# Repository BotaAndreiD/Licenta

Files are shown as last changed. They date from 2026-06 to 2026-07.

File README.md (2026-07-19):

# CardioMed — Portable ECG Acquisition & Monitoring System

**Bachelor's Thesis · Technical University of Cluj-Napoca**
Faculty of Electronics, Telecommunications and Information Technology — 2026

A low-cost, single-lead ECG acquisition and monitoring system built around a **discrete analog front-end** instead of an integrated AFE chip — designed to meet the essential requirements of **IEC 60601-2-25** while staying affordable enough for continuous home use.

---

## Overview

Clinical-grade electrocardiographs remain largely confined to hospitals due to their cost and complexity. CardioMed explores an alternative: a fully discrete analog signal chain — individually optimized filter stages, an instrumentation amplifier, and an active common-mode rejection loop — paired with a companion desktop application that detects heartbeats in real time and generates clinical reports automatically.

Every design decision, from a single capacitor value to the ADC sample rate, is traced back to a specific requirement of the medical standard — a principle referred to throughout the project as **vertical traceability**.

## Key Results

| Parameter | Standard Requirement (IEC 60601-2-25) | Achieved |
|---|---|---|
| Input-referred noise | ≤ 30 µV p-p | **10.76 µV** |
| Passband | 50 mHz – 150 Hz | 49.67 mHz – 150.71 Hz |
| System CMRR | ≥ 89 dB | **123 – 137 dB** |
| Defibrillation protection | ≥ 5000 V | 5000 V |
| Patient fault current | ≤ 10 µA | **3.3 µA** |
| R-wave detection sensitivity (MIT-BIH) | — | **91.5%** |
| Unit cost (BOM, 1,000 units) | — | **~130 RON** |

## System Architecture

```mermaid
flowchart LR
    A[ECG Electrodes] --> B[Protection Network]
    B --> C[Right Leg Drive Loop]
    B --> D["Instrumentation Amplifier (MAX41400)"]
    D --> E["Active Filters: Bessel HPF + Twin-T Notch + Butterworth LPF"]
    E --> F["24-bit ADC (AD7124-4)"]
    F --> G["ESP32-C3 — BLE Transmission"]
    G --> H["Desktop App (C# / WPF)"]
    H --> I["PQRST Detection + Clinical Report (PDF)"]
```

- **Analog front-end** — two-stage TVS/Zener input protection, a Right Leg Drive loop for active common-mode cancellation, a MAX41400 instrumentation amplifier, and a cascade of Bessel high-pass, Twin-T notch, and Butterworth low-pass active filters.
- **Digitization & wireless link** — 24-bit AD7124-4 ADC feeding an ESP32-C3, streaming digitized ECG samples over Bluetooth Low Energy.
- **PCB** — compact 4-layer board (82×46 mm) designed in KiCad, with physically separated analog and digital domains and length-matched differential input traces.
- **Desktop application** — a C#/WPF app performing real-time PQRST detection (Pan–Tompkins-derived algorithm), computing 7 clinical parameters (heart rate, PR/QRS/QTc intervals, SDNN, R-wave amplitude, ectopic-beat count), and auto-generating signed PDF reports.
- **Validation** — the full analog chain was validated in LTSpice against a real ECG signal (MIT-BIH Normal Sinus Rhythm Database) with a realistic interference model; the detection algorithms were separately validated against the public MIT-BIH Arrhythmia and QT Databases (PhysioNet).

## Repository Structure

```
├── AchizitionareSemnal/         # Signal acquisition & analysis
├── Documentatie/                # Full thesis document & synthesis
├── ESP32BLE+InterfataDigitala/  # ESP32-C3 firmware, BLE link, and the C#/WPF monitoring app
├── PCB_REVC/                    # KiCad schematic, PCB layout, and Gerbers
├── SimulariLtspice/             # LTSpice simulations of the analog chain
├── SSET/                        # Student symposium presentation materials
└── Licenta_EA_TST_2024-2025/    # Project archive
```

## Tools & Technologies

`LTspice` · `KiCad` · `Embedded C` · `Python` · `C# / WPF` · `Bluetooth Low Energy` · `MIT-BIH / PhysioNet datasets`

## Standards

Designed against **IEC 60601-2-25** (electrocardiograph performance) and **IEC 60601-1** (basic electrical safety).

## Author

**Bota Andrei-Daniel** — Applied Electronics, Technical University of Cluj-Napoca
[GitHub](https://github.com/BotaAndreiD) · [LinkedIn](https://www.linkedin.com/in/andrei-bota-283269297/)

## Acknowledgments

Thanks to my thesis advisor and to Analog Devices, where an earlier internship shaped much of the analog design approach used in this project.

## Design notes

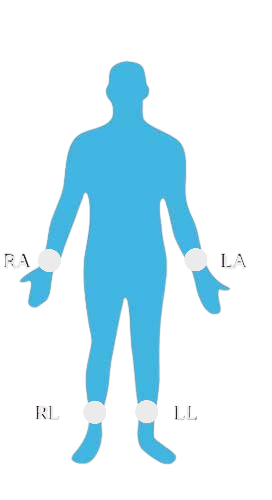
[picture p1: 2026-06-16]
ESP32BLE+InterfataDigitala/ECGMonitor/electrod1.png

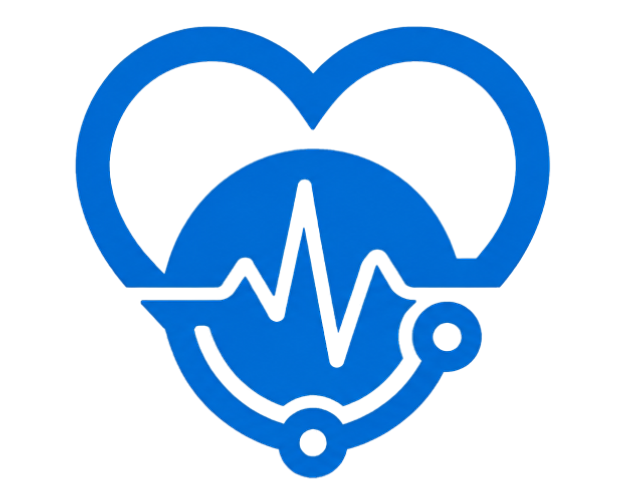
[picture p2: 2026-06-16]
ESP32BLE+InterfataDigitala/ECGMonitor/Sigla.png

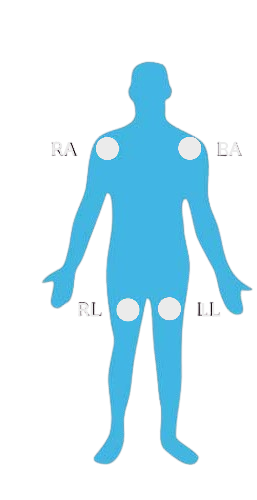
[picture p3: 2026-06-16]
ESP32BLE+InterfataDigitala/ECGMonitor/electrod2.png

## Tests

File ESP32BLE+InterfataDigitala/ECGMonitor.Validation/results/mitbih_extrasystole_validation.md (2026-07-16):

Validare detecție extrasistole (bătăi premature/ectopice) — MIT-BIH Arrhythmia Database (44 înregistrări, fereastră de potrivire ±100 ms)

| Înregistrare | Bătăi reale | Detectate | TP | FN | FP | Se (%) | +P (%) |
|---|---|---|---|---|---|---|---|
| 101 | 3 | 9 | 2 | 1 | 7 | 66.67 | 22.22 |
| 106 | 520 | 309 | 269 | 251 | 40 | 51.73 | 87.06 |
| 108 | 23 | 60 | 9 | 14 | 51 | 39.13 | 15.00 |
| 109 | 40 | 5 | 3 | 37 | 2 | 7.50 | 60.00 |
| 112 | 2 | 4 | 1 | 1 | 3 | 50.00 | 25.00 |
| 114 | 59 | 38 | 2 | 57 | 36 | 3.39 | 5.26 |
| 115 | 0 | 3 | 0 | 0 | 3 | 0.00 | 0.00 |
| 116 | 110 | 115 | 106 | 4 | 9 | 96.36 | 92.17 |
| 118 | 112 | 43 | 29 | 83 | 14 | 25.89 | 67.44 |
| 119 | 444 | 432 | 429 | 15 | 3 | 96.62 | 99.31 |
| 122 | 0 | 1 | 0 | 0 | 1 | 0.00 | 0.00 |
| 124 | 83 | 6 | 0 | 83 | 6 | 0.00 | 0.00 |
| 201 | 328 | 149 | 50 | 278 | 99 | 15.24 | 33.56 |
| 203 | 447 | 415 | 75 | 372 | 340 | 16.78 | 18.07 |
| 205 | 85 | 37 | 18 | 67 | 19 | 21.18 | 48.65 |
| 207 | 212 | 179 | 72 | 140 | 107 | 33.96 | 40.22 |
| 208 | 1367 | 357 | 342 | 1025 | 15 | 25.02 | 95.80 |
| 209 | 384 | 46 | 25 | 359 | 21 | 6.51 | 54.35 |
| 215 | 168 | 135 | 106 | 62 | 29 | 63.10 | 78.52 |
| 220 | 94 | 29 | 26 | 68 | 3 | 27.66 | 89.66 |
| 223 | 560 | 97 | 90 | 470 | 7 | 16.07 | 92.78 |
| 230 | 1 | 8 | 0 | 1 | 8 | 0.00 | 0.00 |
| 100 | 34 | 21 | 20 | 14 | 1 | 58.82 | 95.24 |
| 103 | 2 | 5 | 0 | 2 | 5 | 0.00 | 0.00 |
| 105 | 41 | 84 | 37 | 4 | 47 | 90.24 | 44.05 |
| 111 | 1 | 0 | 0 | 1 | 0 | 0.00 | 0.00 |
| 113 | 6 | 5 | 0 | 6 | 5 | 0.00 | 0.00 |
| 117 | 1 | 4 | 0 | 1 | 4 | 0.00 | 0.00 |
| 121 | 2 | 25 | 1 | 1 | 24 | 50.00 | 4.00 |
| 123 | 3 | 2 | 0 | 3 | 2 | 0.00 | 0.00 |
| 200 | 858 | 217 | 188 | 670 | 29 | 21.91 | 86.64 |
| 202 | 75 | 79 | 38 | 37 | 41 | 50.67 | 48.10 |
| 210 | 226 | 155 | 91 | 135 | 64 | 40.27 | 58.71 |
| 212 | 0 | 7 | 0 | 0 | 7 | 0.00 | 0.00 |
| 213 | 610 | 300 | 288 | 322 | 12 | 47.21 | 96.00 |
| 214 | 257 | 205 | 184 | 73 | 21 | 71.60 | 89.76 |
| 219 | 72 | 95 | 26 | 46 | 69 | 36.11 | 27.37 |
| 221 | 396 | 358 | 314 | 82 | 44 | 79.29 | 87.71 |
| 222 | 209 | 259 | 113 | 96 | 146 | 54.07 | 43.63 |
| 228 | 365 | 366 | 320 | 45 | 46 | 87.67 | 87.43 |
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
| **TOTAL** | | | **3768** | **6719** | **1503** | **35.93** | **71.49** |

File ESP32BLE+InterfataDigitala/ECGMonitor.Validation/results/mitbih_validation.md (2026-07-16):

Validare detector R — MIT-BIH Arrhythmia Database (44 înregistrări, fereastră de potrivire ±100 ms)

| Înregistrare | Bătăi reale | Detectate | TP | FN | FP | Se (%) | +P (%) |
|---|---|---|---|---|---|---|---|
| 101 | 1865 | 1852 | 1843 | 22 | 9 | 98.82 | 99.51 |
| 106 | 2027 | 2008 | 1885 | 142 | 123 | 92.99 | 93.87 |
| 108 | 1763 | 2357 | 1463 | 300 | 894 | 82.98 | 62.07 |
| 109 | 2532 | 2492 | 2128 | 404 | 364 | 84.04 | 85.39 |
| 112 | 2539 | 2517 | 2488 | 51 | 29 | 97.99 | 98.85 |
| 114 | 1879 | 1872 | 1618 | 261 | 254 | 86.11 | 86.43 |
| 115 | 1953 | 1936 | 1917 | 36 | 19 | 98.16 | 99.02 |
| 116 | 2412 | 2391 | 2369 | 43 | 22 | 98.22 | 99.08 |
| 118 | 2278 | 2267 | 1561 | 717 | 706 | 68.53 | 68.86 |
| 119 | 1987 | 1983 | 1976 | 11 | 7 | 99.45 | 99.65 |
| 122 | 2476 | 2436 | 2435 | 41 | 1 | 98.34 | 99.96 |
| 124 | 1619 | 1539 | 1500 | 119 | 39 | 92.65 | 97.47 |
| 201 | 1963 | 1885 | 1778 | 185 | 107 | 90.58 | 94.32 |
| 203 | 2980 | 3041 | 2738 | 242 | 303 | 91.88 | 90.04 |
| 205 | 2656 | 2630 | 2578 | 78 | 52 | 97.06 | 98.02 |
| 207 | 2332 | 2276 | 762 | 1570 | 1514 | 32.68 | 33.48 |
| 208 | 2955 | 2924 | 2902 | 53 | 22 | 98.21 | 99.25 |
| 209 | 3005 | 3009 | 2915 | 90 | 94 | 97.00 | 96.88 |
| 215 | 3363 | 3360 | 3051 | 312 | 309 | 90.72 | 90.80 |
| 220 | 2048 | 2033 | 1976 | 72 | 57 | 96.48 | 97.20 |
| 223 | 2605 | 2557 | 2330 | 275 | 227 | 89.44 | 91.12 |
| 230 | 2256 | 2217 | 1873 | 383 | 344 | 83.02 | 84.48 |
| 100 | 2273 | 2259 | 2255 | 18 | 4 | 99.21 | 99.82 |
| 103 | 2084 | 2040 | 2034 | 50 | 6 | 97.60 | 99.71 |
| 105 | 2572 | 2603 | 2507 | 65 | 96 | 97.47 | 96.31 |
| 111 | 2124 | 2051 | 2018 | 106 | 33 | 95.01 | 98.39 |
| 113 | 1795 | 1789 | 1733 | 62 | 56 | 96.55 | 96.87 |
| 117 | 1535 | 1529 | 1228 | 307 | 301 | 80.00 | 80.31 |
| 121 | 1863 | 1854 | 1826 | 37 | 28 | 98.01 | 98.49 |
| 123 | 1518 | 1493 | 1405 | 113 | 88 | 92.56 | 94.11 |
| 200 | 2601 | 2654 | 1973 | 628 | 681 | 75.86 | 74.34 |
| 202 | 2136 | 2121 | 2106 | 30 | 15 | 98.60 | 99.29 |
| 210 | 2650 | 2653 | 2546 | 104 | 107 | 96.08 | 95.97 |
| 212 | 2748 | 2753 | 2729 | 19 | 24 | 99.31 | 99.13 |
| 213 | 3251 | 3225 | 3179 | 72 | 46 | 97.79 | 98.57 |
| 214 | 2262 | 2222 | 2170 | 92 | 52 | 95.93 | 97.66 |
| 219 | 2154 | 2133 | 2129 | 25 | 4 | 98.84 | 99.81 |
| 221 | 2427 | 2416 | 2406 | 21 | 10 | 99.13 | 99.59 |
| 222 | 2483 | 2487 | 2452 | 31 | 35 | 98.75 | 98.59 |
| 228 | 2053 | 2116 | 1971 | 82 | 145 | 96.01 | 93.15 |
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
| **TOTAL** | | | **92634** | **8571** | **8476** | **91.53** | **91.62** |

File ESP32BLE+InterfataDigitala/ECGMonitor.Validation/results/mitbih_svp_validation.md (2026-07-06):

Validare detecție extrasistole SUPRAVENTRICULARE (nodal/atrial) — MIT-BIH Arrhythmia Database. NOTĂ: +P e o limită inferioară — o detecție care corespunde corect unei bătăi ventriculare (V/aberant/fuziune, cod 4/5/6) apare aici drept FP. (44 înregistrări, fereastră de potrivire ±100 ms)

| Înregistrare | Bătăi reale | Detectate | TP | FN | FP | Se (%) | +P (%) |
|---|---|---|---|---|---|---|---|
| 101 | 3 | 9 | 2 | 1 | 7 | 66.67 | 22.22 |
| 106 | 0 | 309 | 0 | 0 | 309 | 0.00 | 0.00 |
| 108 | 4 | 60 | 3 | 1 | 57 | 75.00 | 5.00 |
| 109 | 0 | 5 | 0 | 0 | 5 | 0.00 | 0.00 |
| 112 | 2 | 4 | 1 | 1 | 3 | 50.00 | 25.00 |
| 114 | 12 | 38 | 1 | 11 | 37 | 8.33 | 2.63 |
| 115 | 0 | 3 | 0 | 0 | 3 | 0.00 | 0.00 |
| 116 | 1 | 115 | 1 | 0 | 114 | 100.00 | 0.87 |
| 118 | 96 | 43 | 17 | 79 | 26 | 17.71 | 39.53 |
| 119 | 0 | 432 | 0 | 0 | 432 | 0.00 | 0.00 |
| 122 | 0 | 1 | 0 | 0 | 1 | 0.00 | 0.00 |
| 124 | 31 | 6 | 0 | 31 | 6 | 0.00 | 0.00 |
| 201 | 31 | 149 | 19 | 12 | 130 | 61.29 | 12.75 |
| 203 | 0 | 415 | 0 | 0 | 415 | 0.00 | 0.00 |
| 205 | 3 | 37 | 1 | 2 | 36 | 33.33 | 2.70 |
| 207 | 107 | 179 | 0 | 107 | 179 | 0.00 | 0.00 |
| 208 | 2 | 357 | 0 | 2 | 357 | 0.00 | 0.00 |
| 209 | 383 | 46 | 25 | 358 | 21 | 6.53 | 54.35 |
| 215 | 3 | 135 | 2 | 1 | 133 | 66.67 | 1.48 |
| 220 | 94 | 29 | 26 | 68 | 3 | 27.66 | 89.66 |
| 223 | 72 | 97 | 8 | 64 | 89 | 11.11 | 8.25 |
| 230 | 0 | 8 | 0 | 0 | 8 | 0.00 | 0.00 |
| 100 | 33 | 21 | 20 | 13 | 1 | 60.61 | 95.24 |
| 103 | 2 | 5 | 0 | 2 | 5 | 0.00 | 0.00 |
| 105 | 0 | 84 | 0 | 0 | 84 | 0.00 | 0.00 |
| 111 | 0 | 0 | 0 | 0 | 0 | 0.00 | 0.00 |
| 113 | 0 | 5 | 0 | 0 | 5 | 0.00 | 0.00 |
| 117 | 1 | 4 | 0 | 1 | 4 | 0.00 | 0.00 |
| 121 | 1 | 25 | 1 | 0 | 24 | 100.00 | 4.00 |
| 123 | 0 | 2 | 0 | 0 | 2 | 0.00 | 0.00 |
| 200 | 30 | 217 | 0 | 30 | 217 | 0.00 | 0.00 |
| 202 | 36 | 79 | 25 | 11 | 54 | 69.44 | 31.65 |
| 210 | 0 | 155 | 0 | 0 | 155 | 0.00 | 0.00 |
| 212 | 0 | 7 | 0 | 0 | 7 | 0.00 | 0.00 |
| 213 | 25 | 300 | 12 | 13 | 288 | 48.00 | 4.00 |
| 214 | 0 | 205 | 0 | 0 | 205 | 0.00 | 0.00 |
| 219 | 7 | 95 | 1 | 6 | 94 | 14.29 | 1.05 |
| 221 | 0 | 358 | 0 | 0 | 358 | 0.00 | 0.00 |
| 222 | 209 | 259 | 113 | 96 | 146 | 54.07 | 43.63 |
| 228 | 3 | 366 | 1 | 2 | 365 | 33.33 | 0.27 |
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
| **TOTAL** | | | **315** | **2316** | **4956** | **11.97** | **5.98** |

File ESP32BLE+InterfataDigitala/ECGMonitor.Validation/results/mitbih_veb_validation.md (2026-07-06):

Validare detecție extrasistole VENTRICULARE (V/aberant/fuziune) — MIT-BIH Arrhythmia Database. NOTĂ: +P e o limită inferioară — o detecție care corespunde corect unei bătăi supraventriculare (J/A/S, cod 7/8/9) apare aici drept FP, deși e o detecție reală a algoritmului, doar în afara acestui subset ventricular. (44 înregistrări, fereastră de potrivire ±100 ms)

| Înregistrare | Bătăi reale | Detectate | TP | FN | FP | Se (%) | +P (%) |
|---|---|---|---|---|---|---|---|
| 101 | 0 | 9 | 0 | 0 | 9 | 0.00 | 0.00 |
| 106 | 520 | 309 | 269 | 251 | 40 | 51.73 | 87.06 |
| 108 | 19 | 60 | 6 | 13 | 54 | 31.58 | 10.00 |
| 109 | 40 | 5 | 3 | 37 | 2 | 7.50 | 60.00 |
| 112 | 0 | 4 | 0 | 0 | 4 | 0.00 | 0.00 |
| 114 | 47 | 38 | 1 | 46 | 37 | 2.13 | 2.63 |
| 115 | 0 | 3 | 0 | 0 | 3 | 0.00 | 0.00 |
| 116 | 109 | 115 | 105 | 4 | 10 | 96.33 | 91.30 |
| 118 | 16 | 43 | 12 | 4 | 31 | 75.00 | 27.91 |
| 119 | 444 | 432 | 429 | 15 | 3 | 96.62 | 99.31 |
| 122 | 0 | 1 | 0 | 0 | 1 | 0.00 | 0.00 |
| 124 | 52 | 6 | 0 | 52 | 6 | 0.00 | 0.00 |
| 201 | 297 | 149 | 31 | 266 | 118 | 10.44 | 20.81 |
| 203 | 447 | 415 | 75 | 372 | 340 | 16.78 | 18.07 |
| 205 | 82 | 37 | 17 | 65 | 20 | 20.73 | 45.95 |
| 207 | 105 | 179 | 72 | 33 | 107 | 68.57 | 40.22 |
| 208 | 1365 | 357 | 342 | 1023 | 15 | 25.05 | 95.80 |
| 209 | 1 | 46 | 0 | 1 | 46 | 0.00 | 0.00 |
| 215 | 165 | 135 | 104 | 61 | 31 | 63.03 | 77.04 |
| 220 | 0 | 29 | 0 | 0 | 29 | 0.00 | 0.00 |
| 223 | 488 | 97 | 82 | 406 | 15 | 16.80 | 84.54 |
| 230 | 1 | 8 | 0 | 1 | 8 | 0.00 | 0.00 |
| 100 | 1 | 21 | 0 | 1 | 21 | 0.00 | 0.00 |
| 103 | 0 | 5 | 0 | 0 | 5 | 0.00 | 0.00 |
| 105 | 41 | 84 | 37 | 4 | 47 | 90.24 | 44.05 |
| 111 | 1 | 0 | 0 | 1 | 0 | 0.00 | 0.00 |
| 113 | 6 | 5 | 0 | 6 | 5 | 0.00 | 0.00 |
| 117 | 0 | 4 | 0 | 0 | 4 | 0.00 | 0.00 |
| 121 | 1 | 25 | 0 | 1 | 25 | 0.00 | 0.00 |
| 123 | 3 | 2 | 0 | 3 | 2 | 0.00 | 0.00 |
| 200 | 828 | 217 | 188 | 640 | 29 | 22.71 | 86.64 |
| 202 | 39 | 79 | 13 | 26 | 66 | 33.33 | 16.46 |
| 210 | 226 | 155 | 91 | 135 | 64 | 40.27 | 58.71 |
| 212 | 0 | 7 | 0 | 0 | 7 | 0.00 | 0.00 |
| 213 | 585 | 300 | 276 | 309 | 24 | 47.18 | 92.00 |
| 214 | 257 | 205 | 184 | 73 | 21 | 71.60 | 89.76 |
| 219 | 65 | 95 | 25 | 40 | 70 | 38.46 | 26.32 |
| 221 | 396 | 358 | 314 | 82 | 44 | 79.29 | 87.71 |
| 222 | 0 | 259 | 0 | 0 | 259 | 0.00 | 0.00 |
| 228 | 362 | 366 | 319 | 43 | 47 | 88.12 | 87.16 |
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
| **TOTAL** | | | **3453** | **4403** | **1818** | **43.95** | **65.51** |

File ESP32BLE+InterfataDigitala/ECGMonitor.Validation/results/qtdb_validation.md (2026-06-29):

Validare intervale PR / QRS / QT — QT Database (105 înregistrări, eroare = valoare aplicație − valoare cardiolog, ms)

| Înregistrare | Bătăi adnotate | Bătăi găsite | PR n | PR eroare (ms) | QRS n | QRS eroare (ms) | QT n | QT eroare (ms) |
|---|---|---|---|---|---|---|---|---|
| sel100 | 30 | 6 | 6 | -8.0 ± 10.1 | 6 | -25.3 ± 7.2 | 6 | 0.0 ± 12.0 |
| sel102 | 85 | 29 | 0 | 0.0 ± 0.0 | 29 | -16.8 ± 19.2 | 29 | -15.0 ± 26.2 |
| sel103 | 30 | 14 | 9 | -2.2 ± 21.4 | 14 | -29.4 ± 9.6 | 14 | -96.9 ± 20.1 |
| sel104 | 77 | 10 | 6 | -18.0 ± 64.2 | 10 | 48.4 ± 46.0 | 10 | -66.0 ± 40.9 |
| sel114 | 50 | 1 | 1 | 0.0 ± 0.0 | 1 | -40.0 ± 0.0 | 1 | -124.0 ± 0.0 |
| sel116 | 50 | 30 | 29 | -22.8 ± 34.6 | 30 | 17.7 ± 19.7 | 30 | -60.4 ± 25.2 |
| sel117 | 30 | 16 | 0 | 0.0 ± 0.0 | 16 | 1.2 ± 18.5 | 16 | -70.5 ± 17.8 |
| sel123 | 30 | 13 | 2 | -88.0 ± 12.0 | 13 | 35.1 ± 23.2 | 13 | -27.4 ± 22.9 |
| sel14046 | 31 | 29 | 29 | 37.4 ± 14.5 | 29 | 3.9 ± 12.5 | 29 | -48.3 ± 16.8 |
| sel14157 | 30 | 0 | 0 | 0.0 ± 0.0 | 0 | 0.0 ± 0.0 | 0 | 0.0 ± 0.0 |
| sel14172 | 50 | 4 | 0 | 0.0 ± 0.0 | 4 | -5.0 ± 17.3 | 4 | 46.0 ± 87.2 |
| sel15814 | 30 | 3 | 3 | -58.7 ± 30.9 | 3 | -82.7 ± 34.3 | 3 | -96.0 ± 29.9 |
| sel16265 | 30 | 0 | 0 | 0.0 ± 0.0 | 0 | 0.0 ± 0.0 | 0 | 0.0 ± 0.0 |
| sel16272 | 30 | 29 | 0 | 0.0 ± 0.0 | 29 | -1.2 ± 11.3 | 29 | -56.1 ± 15.0 |
| sel16273 | 30 | 9 | 9 | 70.7 ± 20.9 | 9 | 17.3 ± 18.2 | 9 | -76.9 ± 7.0 |
| sel16420 | 30 | 24 | 24 | -91.0 ± 18.5 | 24 | 34.0 ± 13.9 | 24 | -39.2 ± 18.5 |
| sel16483 | 30 | 4 | 4 | -19.0 ± 13.7 | 4 | -50.0 ± 10.4 | 4 | -100.0 ± 4.9 |
| sel16539 | 30 | 11 | 6 | 15.3 ± 29.2 | 11 | -37.1 ± 6.4 | 11 | -91.6 ± 10.8 |
| sel16773 | 30 | 0 | 0 | 0.0 ± 0.0 | 0 | 0.0 ± 0.0 | 0 | 0.0 ± 0.0 |
| sel16786 | 30 | 2 | 1 | -16.0 ± 0.0 | 2 | 32.0 ± 12.0 | 2 | -68.0 ± 12.0 |
| sel16795 | 30 | 23 | 0 | 0.0 ± 0.0 | 23 | 2.8 ± 10.7 | 23 | -51.3 ± 13.7 |
| sel17152 | 30 | 21 | 21 | -48.6 ± 15.6 | 21 | 21.1 ± 20.4 | 21 | 61.3 ± 27.1 |
| sel17453 | 30 | 15 | 11 | 57.1 ± 18.1 | 15 | -39.5 ± 11.8 | 15 | -81.3 ± 24.8 |
| sel213 | 71 | 1 | 1 | -60.0 ± 0.0 | 1 | -52.0 ± 0.0 | 1 | -12.0 ± 0.0 |
| sel221 | 30 | 21 | 0 | 0.0 ± 0.0 | 21 | 69.3 ± 41.3 | 21 | -48.6 ± 22.2 |
| sel223 | 31 | 9 | 9 | -73.8 ± 24.9 | 9 | 47.1 ± 25.5 | 9 | -57.3 ± 30.9 |
| sel230 | 50 | 13 | 13 | -72.9 ± 36.1 | 13 | 33.2 ± 20.6 | 13 | -29.5 ± 23.1 |
| sel231 | 50 | 25 | 2 | 18.0 ± 14.0 | 25 | 6.2 ± 45.0 | 25 | -113.1 ± 19.9 |
| sel232 | 0 | 0 | 0 | 0.0 ± 0.0 | 0 | 0.0 ± 0.0 | 0 | 0.0 ± 0.0 |
| sel233 | 30 | 22 | 22 | -79.8 ± 14.6 | 22 | 59.6 ± 21.5 | 22 | 60.9 ± 26.0 |
| sel30 | 30 | 0 | 0 | 0.0 ± 0.0 | 0 | 0.0 ± 0.0 | 0 | 0.0 ± 0.0 |
| sel301 | 30 | 28 | 28 | 24.9 ± 25.3 | 28 | -21.6 ± 16.2 | 28 | -74.6 ± 41.2 |
| sel302 | 30 | 28 | 28 | -11.1 ± 20.0 | 28 | -38.1 ± 8.2 | 28 | -84.6 ± 10.7 |
| sel306 | 36 | 4 | 3 | -24.0 ± 15.0 | 4 | 12.0 ± 13.6 | 4 | 188.0 ± 27.0 |
| sel307 | 30 | 21 | 3 | 37.3 ± 3.8 | 21 | -28.8 ± 9.8 | 21 | -115.8 ± 42.7 |
| sel308 | 50 | 47 | 47 | 20.8 ± 20.5 | 47 | -41.9 ± 24.1 | 47 | -56.4 ± 20.5 |
| sel31 | 30 | 0 | 0 | 0.0 ± 0.0 | 0 | 0.0 ± 0.0 | 0 | 0.0 ± 0.0 |
| sel310 | 30 | 5 | 0 | 0.0 ± 0.0 | 5 | -38.4 ± 2.0 | 5 | -92.8 ± 7.8 |
| sel32 | 30 | 24 | 24 | -37.0 ± 26.5 | 24 | 60.0 ± 19.4 | 24 | -28.7 ± 129.2 |
| sel33 | 30 | 6 | 0 | 0.0 ± 0.0 | 6 | -46.0 ± 8.6 | 6 | -225.3 ± 43.6 |
| sel34 | 30 | 2 | 1 | 80.0 ± 0.0 | 2 | 16.0 ± 20.0 | 2 | -98.0 ± 2.0 |
| sel35 | 0 | 0 | 0 | 0.0 ± 0.0 | 0 | 0.0 ± 0.0 | 0 | 0.0 ± 0.0 |
| sel36 | 1 | 0 | 0 | 0.0 ± 0.0 | 0 | 0.0 ± 0.0 | 0 | 0.0 ± 0.0 |
| sel37 | 0 | 0 | 0 | 0.0 ± 0.0 | 0 | 0.0 ± 0.0 | 0 | 0.0 ± 0.0 |
| sel38 | 30 | 13 | 13 | -4.3 ± 16.9 | 13 | -59.1 ± 18.4 | 13 | -26.8 ± 16.0 |
| sel39 | 30 | 23 | 22 | -7.5 ± 31.9 | 23 | -21.9 ± 21.0 | 22 | -65.6 ± 23.7 |
| sel40 | 30 | 0 | 0 | 0.0 ± 0.0 | 0 | 0.0 ± 0.0 | 0 | 0.0 ± 0.0 |
| sel41 | 30 | 0 | 0 | 0.0 ± 0.0 | 0 | 0.0 ± 0.0 | 0 | 0.0 ± 0.0 |
| sel42 | 30 | 0 | 0 | 0.0 ± 0.0 | 0 | 0.0 ± 0.0 | 0 | 0.0 ± 0.0 |
| sel43 | 30 | 0 | 0 | 0.0 ± 0.0 | 0 | 0.0 ± 0.0 | 0 | 0.0 ± 0.0 |
| sel44 | 22 | 0 | 0 | 0.0 ± 0.0 | 0 | 0.0 ± 0.0 | 0 | 0.0 ± 0.0 |
| sel45 | 30 | 0 | 0 | 0.0 ± 0.0 | 0 | 0.0 ± 0.0 | 0 | 0.0 ± 0.0 |
| sel46 | 30 | 2 | 0 | 0.0 ± 0.0 | 2 | 30.0 ± 6.0 | 2 | 0.0 ± 20.0 |
| sel47 | 30 | 0 | 0 | 0.0 ± 0.0 | 0 | 0.0 ± 0.0 | 0 | 0.0 ± 0.0 |
| sel48 | 30 | 0 | 0 | 0.0 ± 0.0 | 0 | 0.0 ± 0.0 | 0 | 0.0 ± 0.0 |
| sel49 | 30 | 2 | 0 | 0.0 ± 0.0 | 2 | 134.0 ± 10.0 | 2 | 110.0 ± 10.0 |
| sel50 | 31 | 1 | 0 | 0.0 ± 0.0 | 1 | 32.0 ± 0.0 | 1 | 156.0 ± 0.0 |
| sel51 | 30 | 9 | 0 | 0.0 ± 0.0 | 9 | 40.9 ± 16.6 | 9 | 43.1 ± 44.4 |
| sel52 | 30 | 25 | 25 | -74.9 ± 28.6 | 25 | 35.5 ± 22.0 | 25 | 96.3 ± 60.0 |
| sel803 | 30 | 16 | 14 | -23.1 ± 24.3 | 16 | -20.2 ± 26.9 | 16 | -82.2 ± 25.2 |
| sel808 | 30 | 0 | 0 | 0.0 ± 0.0 | 0 | 0.0 ± 0.0 | 0 | 0.0 ± 0.0 |
| sel811 | 30 | 13 | 0 | 0.0 ± 0.0 | 13 | 51.4 ± 16.7 | 13 | -26.8 ± 24.5 |
| sel820 | 30 | 6 | 6 | -22.0 ± 16.1 | 6 | 42.0 ± 13.0 | 6 | 29.3 ± 24.6 |
| sel821 | 30 | 15 | 14 | -26.0 ± 56.3 | 15 | 10.9 ± 18.4 | 15 | -36.8 ± 27.3 |
| sel840 | 70 | 61 | 42 | 23.5 ± 43.9 | 61 | -6.1 ± 30.9 | 61 | -71.7 ± 33.8 |
| sel847 | 33 | 5 | 0 | 0.0 ± 0.0 | 5 | 36.0 ± 12.9 | 5 | -44.8 ± 27.9 |
| sel853 | 30 | 0 | 0 | 0.0 ± 0.0 | 0 | 0.0 ± 0.0 | 0 | 0.0 ± 0.0 |
| sel871 | 70 | 0 | 0 | 0.0 ± 0.0 | 0 | 0.0 ± 0.0 | 0 | 0.0 ± 0.0 |
| sel872 | 30 | 12 | 9 | -56.0 ± 25.1 | 12 | -8.0 ± 31.0 | 12 | -73.7 ± 29.7 |
| sel873 | 33 | 11 | 0 | 0.0 ± 0.0 | 11 | 51.6 ± 11.0 | 11 | -9.1 ± 11.5 |
| sel883 | 30 | 10 | 0 | 0.0 ± 0.0 | 10 | -8.4 ± 21.3 | 10 | 23.2 ± 25.3 |
| sel891 | 71 | 1 | 1 | -116.0 ± 0.0 | 1 | 44.0 ± 0.0 | 1 | 52.0 ± 0.0 |
| sele0104 | 30 | 0 | 0 | 0.0 ± 0.0 | 0 | 0.0 ± 0.0 | 0 | 0.0 ± 0.0 |
| sele0106 | 30 | 0 | 0 | 0.0 ± 0.0 | 0 | 0.0 ± 0.0 | 0 | 0.0 ± 0.0 |
| sele0107 | 34 | 0 | 0 | 0.0 ± 0.0 | 0 | 0.0 ± 0.0 | 0 | 0.0 ± 0.0 |
| sele0110 | 30 | 27 | 16 | 15.8 ± 23.4 | 27 | 45.2 ± 18.4 | 27 | -44.0 ± 31.9 |
| sele0111 | 30 | 1 | 1 | 20.0 ± 0.0 | 1 | -16.0 ± 0.0 | 1 | -68.0 ± 0.0 |
| sele0112 | 50 | 0 | 0 | 0.0 ± 0.0 | 0 | 0.0 ± 0.0 | 0 | 0.0 ± 0.0 |
| sele0114 | 30 | 0 | 0 | 0.0 ± 0.0 | 0 | 0.0 ± 0.0 | 0 | 0.0 ± 0.0 |
| sele0116 | 30 | 0 | 0 | 0.0 ± 0.0 | 0 | 0.0 ± 0.0 | 0 | 0.0 ± 0.0 |
| sele0121 | 30 | 29 | 29 | -63.0 ± 14.0 | 29 | 9.4 ± 15.2 | 29 | -31.2 ± 15.7 |
| sele0122 | 30 | 28 | 28 | -52.3 ± 26.9 | 28 | 6.4 ± 9.7 | 28 | -24.4 ± 8.0 |
| sele0124 | 50 | 30 | 30 | -89.9 ± 29.6 | 30 | 30.3 ± 23.9 | 30 | -63.5 ± 34.4 |
| sele0126 | 30 | 3 | 1 | -60.0 ± 0.0 | 3 | 16.0 ± 13.1 | 3 | -29.3 ± 21.7 |
| sele0129 | 30 | 1 | 0 | 0.0 ± 0.0 | 1 | 40.0 ± 0.0 | 1 | -16.0 ± 0.0 |
| sele0133 | 30 | 0 | 0 | 0.0 ± 0.0 | 0 | 0.0 ± 0.0 | 0 | 0.0 ± 0.0 |
| sele0136 | 30 | 0 | 0 | 0.0 ± 0.0 | 0 | 0.0 ± 0.0 | 0 | 0.0 ± 0.0 |
| sele0166 | 36 | 34 | 0 | 0.0 ± 0.0 | 34 | -48.4 ± 9.4 | 34 | -118.0 ± 18.9 |
| sele0170 | 30 | 29 | 0 | 0.0 ± 0.0 | 29 | 18.1 ± 10.6 | 29 | -61.0 ± 21.7 |
| sele0203 | 30 | 2 | 1 | -128.0 ± 0.0 | 2 | 106.0 ± 2.0 | 2 | 64.0 ± 12.0 |
| sele0210 | 30 | 4 | 4 | -3.0 ± 17.3 | 4 | -14.0 ± 10.0 | 4 | -93.0 ± 11.4 |
| sele0211 | 30 | 1 | 1 | -56.0 ± 0.0 | 1 | 4.0 ± 0.0 | 1 | -80.0 ± 0.0 |
| sele0303 | 30 | 0 | 0 | 0.0 ± 0.0 | 0 | 0.0 ± 0.0 | 0 | 0.0 ± 0.0 |
| sele0405 | 30 | 18 | 16 | 3.5 ± 37.9 | 18 | 17.6 ± 12.9 | 18 | -48.4 ± 13.3 |
| sele0406 | 31 | 18 | 14 | 24.0 ± 14.9 | 18 | 11.1 ± 9.8 | 18 | -55.1 ± 9.9 |
| sele0409 | 30 | 25 | 25 | -26.4 ± 40.8 | 25 | -30.1 ± 8.6 | 25 | -33.3 ± 26.5 |
| sele0411 | 30 | 3 | 3 | -30.7 ± 33.5 | 3 | 37.3 ± 8.2 | 3 | -42.7 ± 13.6 |
| sele0509 | 30 | 15 | 15 | -24.3 ± 13.9 | 15 | -2.9 ± 10.0 | 15 | -25.6 ± 13.5 |
| sele0603 | 30 | 0 | 0 | 0.0 ± 0.0 | 0 | 0.0 ± 0.0 | 0 | 0.0 ± 0.0 |
| sele0604 | 30 | 30 | 30 | 20.8 ± 19.4 | 30 | 7.3 ± 11.6 | 30 | -60.3 ± 16.3 |
| sele0606 | 30 | 18 | 18 | -58.9 ± 26.2 | 18 | -12.0 ± 24.0 | 18 | -91.1 ± 33.0 |
| sele0607 | 30 | 1 | 1 | -16.0 ± 0.0 | 1 | 32.0 ± 0.0 | 1 | -48.0 ± 0.0 |
| sele0609 | 30 | 0 | 0 | 0.0 ± 0.0 | 0 | 0.0 ± 0.0 | 0 | 0.0 ± 0.0 |
| sele0612 | 30 | 0 | 0 | 0.0 ± 0.0 | 0 | 0.0 ± 0.0 | 0 | 0.0 ± 0.0 |
| sele0704 | 30 | 29 | 29 | 24.1 ± 28.4 | 29 | -98.1 ± 15.0 | 29 | -88.8 ± 11.0 |
| **TOTAL** | | **750** | **-18.4 ± 50.2** | **1120** | **1.0 ± 40.9** | **1119** | **-48.6 ± 58.2** |

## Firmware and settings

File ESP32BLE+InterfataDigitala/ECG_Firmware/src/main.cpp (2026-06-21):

#include <Arduino.h>
#include <NimBLEDevice.h>
#include <LittleFS.h>

#define SERVICE_UUID "12345678-1234-1234-1234-123456789abc"
#define CHARACTERISTIC_UUID "abcdefab-1234-1234-1234-abcdefabcdef"

NimBLECharacteristic *pCharacteristic = nullptr;
File ecgFile;

class ServerCallbacks : public NimBLEServerCallbacks
{
    void onConnect(NimBLEServer *pServer) override
    {
        Serial.println("Client conectat!");
        pCharacteristic->setValue((const uint8_t *)"CONNECTED", 9);
    }
    void onDisconnect(NimBLEServer *pServer) override
    {
        Serial.println("Client deconectat!");
        NimBLEDevice::startAdvertising();
    }
};

void setup()
{
    Serial.begin(115200);
    delay(1000);
    Serial.println("START");

    bool fsOk = LittleFS.begin(false);
    Serial.println(fsOk ? "LittleFS OK" : "LittleFS FAIL");

    if (fsOk)
    {
        ecgFile = LittleFS.open("/ecg_ble.txt", "r");
        Serial.println(ecgFile ? "Fisier OK" : "Fisier FAIL");
        if (ecgFile)
            ecgFile.readStringUntil('\n');
    }

    NimBLEDevice::init("ECGMonitor");
    NimBLEServer *pServer = NimBLEDevice::createServer();
    pServer->setCallbacks(new ServerCallbacks());

    NimBLEService *pService = pServer->createService(SERVICE_UUID);
    pCharacteristic = pService->createCharacteristic(
        CHARACTERISTIC_UUID,
        NIMBLE_PROPERTY::READ | NIMBLE_PROPERTY::NOTIFY | NIMBLE_PROPERTY::INDICATE);
    pService->start();

    NimBLEAdvertising *pAdvertising = NimBLEDevice::getAdvertising();
    NimBLEAdvertisementData advData;
    advData.setName("ECGMonitor");
    advData.setCompleteServices(NimBLEUUID(SERVICE_UUID));
    pAdvertising->setAdvertisementData(advData);
    NimBLEAdvertisementData scanData;
    scanData.setName("ECGMonitor");
    pAdvertising->setScanResponseData(scanData);
    pAdvertising->start();

    Serial.println("BLE pornit!");
}

void loop()
{
    if (!ecgFile || !ecgFile.available())
    {
        if (ecgFile)
        {
            ecgFile.seek(0);
            ecgFile.readStringUntil('\n');
        }
        delay(100);
        return;
    }

    String line = ecgFile.readStringUntil('\n');
    line.trim();

    if (line.length() > 0)
    {
        pCharacteristic->setValue((const uint8_t *)line.c_str(), line.length());
        pCharacteristic->notify();
        Serial.println("Trimis: " + line.substring(0, 15));
    }

    delay(8);
}

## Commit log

2025-10-21 Am adaugat primele articole aferente lucrarii de licenta
2025-12-21 Track EKG signal with Git LFS
2026-01-10 Adaugat simulari pentru a demonstra functionalitatea circuitului
2026-03-04 -Adaugat simulari extra pentru a dovedi functionalitatea sistemului de achizitie -Simulare pentru zgomotul de 50hz -Simulare pentru offset-ul generat de electrozi -Simulare pentru a dovedi functionar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
2026-03-06 Adaugat simulari aferente pentru a indeplini standardele medicale pentru -Simulare protectie pentru supratensiune de la defibrilator -Adaugat simulare de stress test in care au fost modelate toate ne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
2026-03-24 Modificat RLD circuit
2026-04-06 Adaugat fisierele aferente PCB
    [2035-09-sm-rplf.stp, AD7124-4BRUZ.STEP, ADP151AUJZ-3.3-R7.STEP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]
2026-04-07 Modificat pcb ul cu scopul de a adauga test point uri
    [PCB.kicad_pcb, PCB.kicad_sch]
2026-04-08 Modificat pcb
    [PCB.kicad_pcb, PCB.kicad_sch]
2026-04-08 Remodificat un pin de testpoint
    [PCB.kicad_pcb, PCB.kicad_sch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]
2026-04-10 Ultimele modificari a iteratiei A pentru PCB inainte de comanda
    [PCB-B_Cu.gbr, PCB-B_Mask.gbr, PCB-B_Paste.gbr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]
2026-05-05 Adaugat simulari pentru a testa impacul tolerantei asupra sistemului de achizitie
    [PCB.csv]
2026-06-09 Adaugat adc si uc la pcb
    [ESP32-C3_SUPERMINI_TH.step, PCB.kicad_pcb, PCB.kicad_sch]
2026-06-11 Modificat la ultima iteratie PCB-ul
    [2035-09-sm-rplf.stp, AD7124-4BRUZ.STEP, ADP151AUJZ-3.3-R7.STEP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]
2026-06-16 Adaugat ultima iteratie a PCB-ului si realizat interfata grafica
    [PCB-B_Cu.gbr, PCB-B_Mask.gbr, PCB-B_Paste.gbr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]
2026-06-21 Modificat interfata si adaugat compatibilitae BLE esp32-c3 supermini
2026-06-29 Adaugat PanTompkins detectie
    [PCB.kicad_sch, PretComponente.csv]
2026-06-29 Adaugat validarea agloritmilor de calcul a parametrilor ecg din interfata
    [mitbih_extrasystole_validation.csv, mitbih_validation.csv, qtdb_validation.csv]
2026-07-01 Modificat algoritm detectie R si extrasistole pentru a imbunatiti se si pe detectie extrasistole pana la 35% de la 29%
    [mitbih_extrasystole_validation.csv, mitbih_validation.csv, qtdb_validation.csv]
2026-07-06 Fix embedded repository and add all files
    [2035-09-sm-rplf.stp, AD7124-4BRUZ.STEP, ADP151AUJZ-3.3-R7.STEP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]
2026-07-14 Pregatit simulare pentru prezentare in fata comisiei
    [2035-09-sm-rplf.stp, AD7124-4BRUZ.STEP, ADP151AUJZ-3.3-R7.STEP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]
2026-07-16 Adaugat datele pacientului 207 care prezinta cea mai mica detectie a undei R pentru a se observa in interfata
    [mitbih_extrasystole_validation.csv, mitbih_validation.csv]
